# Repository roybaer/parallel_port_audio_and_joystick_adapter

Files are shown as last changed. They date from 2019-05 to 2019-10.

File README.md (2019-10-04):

# Parallel port audio and joystick adapter

These are KiCAD and Inkscape design files for an improved FTL Sound Adapter compatible parallel port audio and joystick adapter.

This particular design adds series resistors to prevent a joystick connected to the expansion port from shorting out parallel port lines.

## Photo

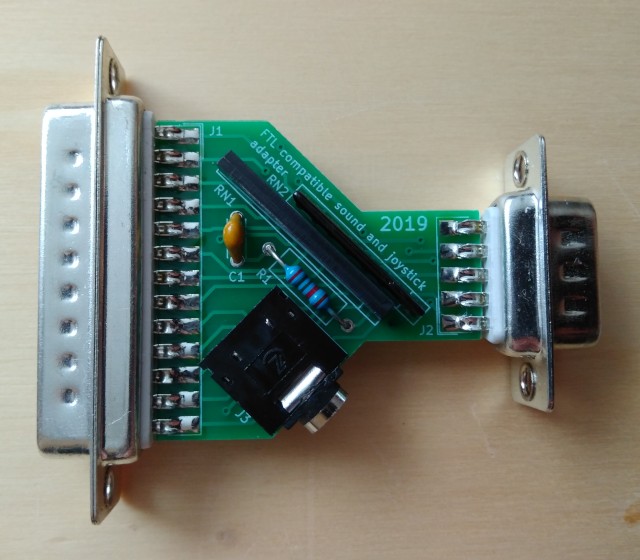
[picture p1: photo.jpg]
Photo of the opened device


## License

This work is licensed under the Creative Commons Attribution-ShareAlike 4.0 International License. To view a copy of this license, visit http://creativecommons.org/licenses/by-sa/4.0/ or send a letter to Creative Commons, PO Box 1866, Mountain View, CA 94042, USA.

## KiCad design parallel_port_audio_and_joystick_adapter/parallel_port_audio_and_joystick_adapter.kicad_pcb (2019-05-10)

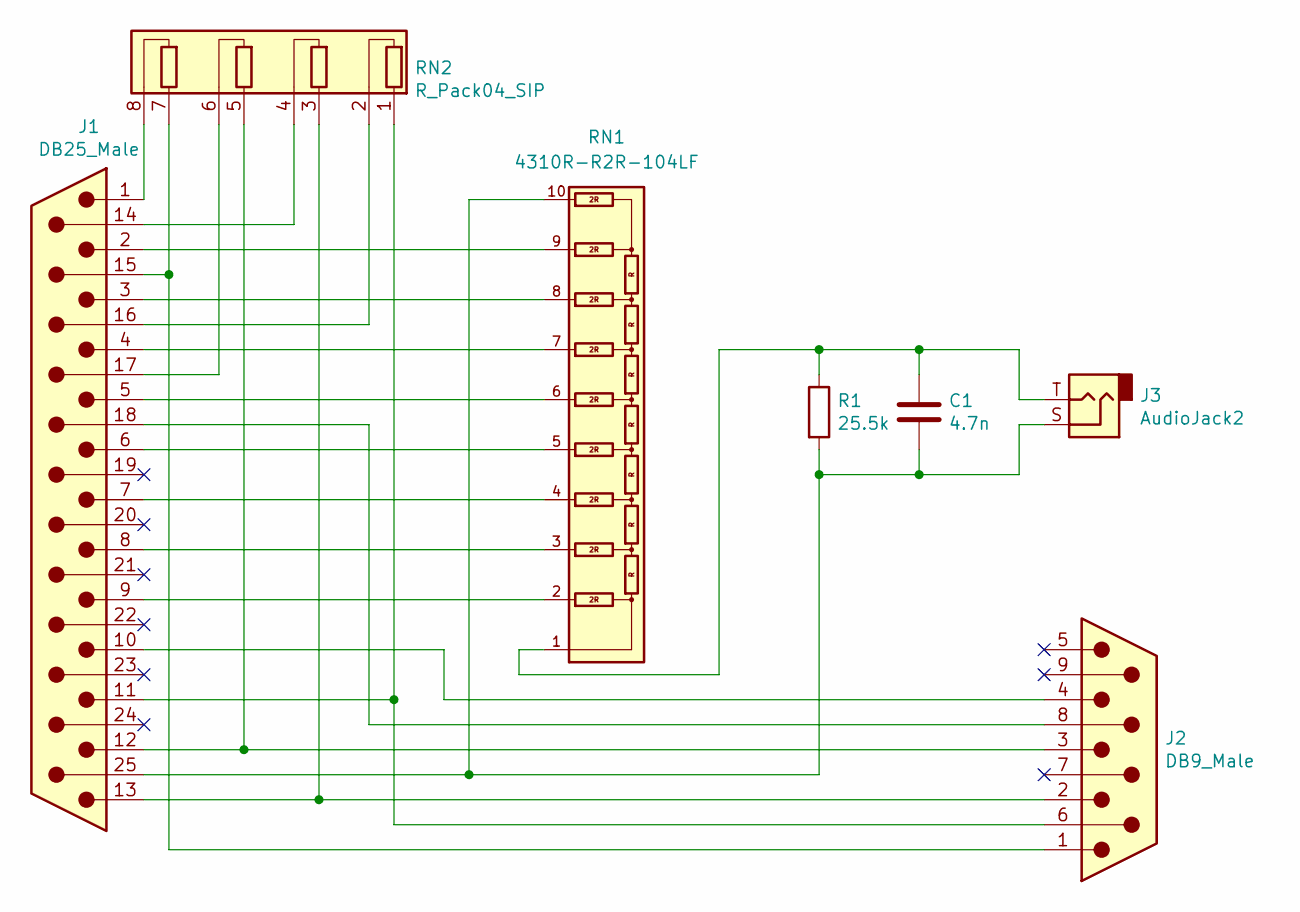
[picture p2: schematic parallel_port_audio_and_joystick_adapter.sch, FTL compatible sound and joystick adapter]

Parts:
C1: 4.7n; C_Disc_D4.3mm_W1.9mm_P5.00mm
J1: DB25_Male; DSUB-25_Male_EdgeMount_P2.77mm
J2: DB9_Male; DSUB-9_Male_EdgeMount_P2.77mm
J3: AudioJack2; Jack_3.5mm_CUI_SJ1-3525N_Horizontal
R1: 25.5k; R_Axial_DIN0309_L9.0mm_D3.2mm_P12.70mm_Horizontal
RN1: 4310R-R2R-104LF; R_Array_SIP10
RN2: R_Pack04_SIP; R_Array_SIP8

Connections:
unnamed: C1.1, J3.T, R1.1, RN1.1
unnamed: C1.2, J1.25, J3.S, R1.2, RN1.10
unnamed: J1.1, RN2.8 (R4.2)
unnamed: J1.2, RN1.9
unnamed: J1.3, RN1.8
unnamed: J1.4, RN1.7
unnamed: J1.5, RN1.6
unnamed: J1.6, RN1.5
unnamed: J1.7, RN1.4
unnamed: J1.8, RN1.3
unnamed: J1.9, RN1.2
unnamed: J1.10, J2.4
unnamed: J1.11, J2.6, RN2.1 (R1.1)
unnamed: J1.12, J2.3, RN2.5 (R3.1)
unnamed: J1.13, J2.2, RN2.3 (R2.1)
unnamed: J1.14, RN2.4 (R2.2)
unnamed: J1.15, J2.1, RN2.7 (R4.1)
unnamed: J1.16, RN2.2 (R1.2)
unnamed: J1.17, RN2.6 (R3.2)
unnamed: J1.18, J2.8

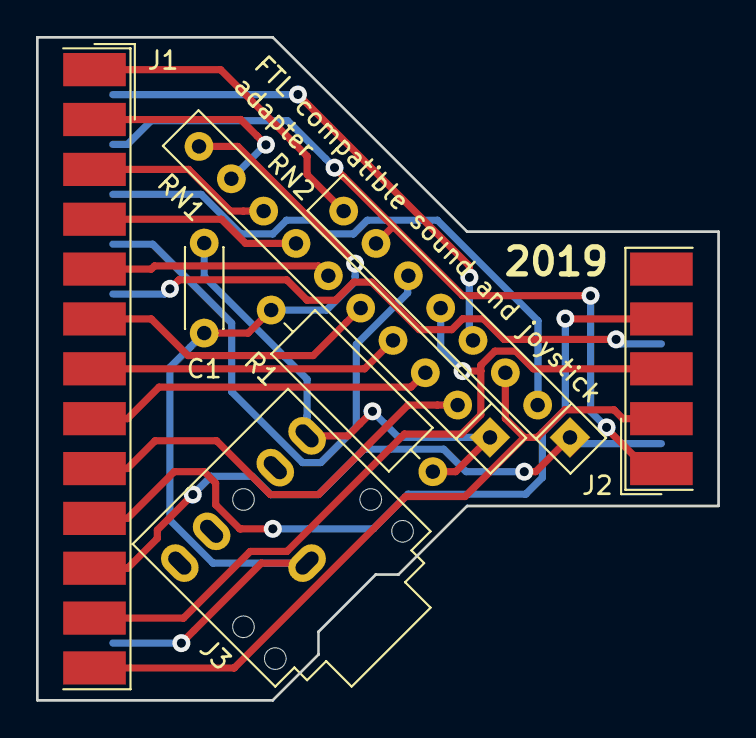
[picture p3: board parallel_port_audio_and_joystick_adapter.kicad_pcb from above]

Board: 2 copper layers, 37.8 x 36.8 mm, 7 parts (0 on the bottom side), 20 nets.

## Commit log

2019-04-07 add resistors in series to prevent short circuit
    [parallel_port_audio_and_joystick_adapter.kicad_pcb, parallel_port_audio_and_joystick_adapter.sch]
2019-05-10 move traces further away from holes
    [parallel_port_audio_and_joystick_adapter.kicad_pcb]
